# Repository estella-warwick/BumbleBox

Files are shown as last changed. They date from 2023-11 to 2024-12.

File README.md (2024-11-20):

# The BumbleBox: an open-source platform for collecting and quantifying behavior in bumblebees

MastersFigure1final_lowres

https://github.com/Crall-Lab/BumbleBox/assets/102829182/df6746e8-be8d-474d-97e5-7dcfe8cf2d3f

https://github.com/Crall-Lab/BumbleBox/assets/102829182/92d87284-6381-4c2a-ad78-1d7bee3951b9

## About the BumbleBox

xyz
<br /><br />

## Animations of BumbleBox construction

Youtube link to the animations playlist here: [here](https://www.youtube.com/playlist?list=PLHFFPE_W56kkKZQcCbZdQC42oRvphlQpn)
<br /><br />
## BumbleBox Construction Instructions

See building instructions in a google document [here](https://docs.google.com/document/d/14RvdYWr2pkWZVl2kxIvVvCeMsCQhhuTJNkAIiLYHth8/edit?usp=sharing)
<br /><br />

## Software Installation and Setup

See instruction videos [here](https://www.youtube.com/channel/UCykbaZYtgNcFspMfKnfSwYA)
The below steps 1-4 are walked through in the video tutorials 

### Raspberry Pi Install

<br />

Installed using the following hardware:
- Rasbperry Pi 4b, 8GB RAM
- 32GB SanDisk Ultra SD card
- Monitor with HDMI
- HDMI to micro-HDMI cable

<br />

1. Download Debian Bookworm 64-bit OS onto your SD card using a computer with the Raspberry Pi Imager application (Download the application here: https://www.raspberrypi.com/software/)
   
2. Put the SD card into the Pi's SD card slot, hook the Pi up to a monitor via a micro-HDMI to HDMI cable, and power the Pi on - you should see the operating system load on the screen
   
3. You will need to create a username and password for the Raspberry Pi - IMPORTANT: use 'pi' for the username, and some password you'll remember

4. Change your computer hostname to " bumblebox-XX " ex. " bumblebox-01 " or " bumblebox-11 " if you don't know how to do this on the Raspberry Pi, see this [video](https://www.youtube.com/watch?v=NSkHLyY-83s) 
   
5. Open a terminal window (look for a button on the top left of the screen that looks like a black box with a blue top and white text inside it showing '>_')

6. We're now going to install the required software to use the BumbleBox code. For each of the following commands, type the command (or copy and paste) into the terminal window, and then press enter. Once you enter the command, the computer may take some time to download the required software, and will show a lot of text on the screen. Wait for each command to finish running before attempting to run the next command.

<br /><br />

```bash
pip3 install opencv-contrib-python --break-system-packages
```

```bash
pip3 install pandas --break-system-packages
```

```bash
pip3 install scipy --break-system-packages
```

```bash
pip3 install python-crontab --break-system-packages
```

```bash
pip3 install scikit-video --break-system-packages
```

```bash
pip3 install dask --break-system-packages
```
<br />
Amazing! You have now downloaded all the necessary packages to run the BumbleBox on the Raspberry Pi.
<br /><br />
6. Next, download the BumbleBox code onto your Raspberry Pi.  To download the code, click the green 'Code' button on the main BumbleBox page and then press the 'Download Zip' button. After downloading the folder onto the Pi and unzipping it, you might want to put the folder onto the Pi's Desktop so you can access it easily.

download-zip-example-github

<br /><br />

### Install labelling software (on a separate computer, not the Raspberry Pi - install instructions tested for Mac and Linux computers so far) - this is included in the software and setup section, but this will only be used after data is collected, so it does not need to be completed prior to using the BumbleBox.

#### The BumbleBox generates nest images daily that can be labelled in order to track different nest components, which can be useful for a variety of interesting research questions. To do this, we need to install the BumbleBox code and the labelling software we will use on a separate computer. 

1. Install BumbleBox code onto your computer, in the same manner as above

2. Open a terminal window on your computer (try typing 'terminal' into your computer search bar to find it, or go to your applications page and search for the terminal app)

3. Type the following command to create what is called a virtual environment, which basically creates an isolated place on your computer to download software so that it won't potentially cause conflicts with other software on your computer. The virtual environment we're creating is called labelme, because we will be downloading software called labelme.

```bash
python3 -m venv labelme
```

4. Now we have to 'go into' the virtual environment that we've created, using this command:

```bash
source labelme/bin/activate
```

Your terminal should now look something like this:

virtual-env-tutorial-pic

Now we're ready to install labelme! Run the following command in the same terminal window after entering the virtual environment:

```bash
pip3 install labelme
```

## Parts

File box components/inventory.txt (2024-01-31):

Laser cut components for 1/8" acrylic
The component files are duplicated as svg, pdf, and dxf files for ease of use by whoever is cutting them. Some laser cutters work better with a particular kind of file format. 

1x clear_top - clear acrylic
1x diffuser_top - clear acrylic
1x opaque_top - white acrylic
1x access_door_wall - white acrylic
1x entrance_wall - white acrylic
2x vent_walls - white acrylic
1x wall - white acrylic
1x feeder_base - white acrylic

The entrance wall file and the wall file are interchangeable depending on whether the entrance
Part is being used or not (ie whether the bees are going to be let out of the nest or not). I recommend cutting both so you have both options.

The diffuser_top file has 2 different laser path intensities - one to cut the top out, and one to score it in a checkerboard pattern. Each laser cutter is different, so it is hard to give direct settings. For the scoring paths of the diffuser_top file, we want a cut probably 1/4 - 1/3 of the way through the clear 1/8" acrylic. We want to avoid warping. For those getting these cut commercially, you should let the people know that about this file.

3D printed components

All parts should be printed with a 0.4mm nozzle at 0.15mm layer height and automatic supports.
For each box we need these number of printed components:

1x base_insert.stl
1x base.stl
4x bottom_wall_connector.3mf
1x camera_mount.3mf
1x custom_box_entrance.3mf
3x entrance_inner_door.3mf
1x imaging_top_side_innie.3mf
1x imaging_top_side_outie.3mf
1x latch_key.stl
2x latch.stl
4x box_foot.3mf
3x outer_door.3mf
4x top_wall_connector.3mf

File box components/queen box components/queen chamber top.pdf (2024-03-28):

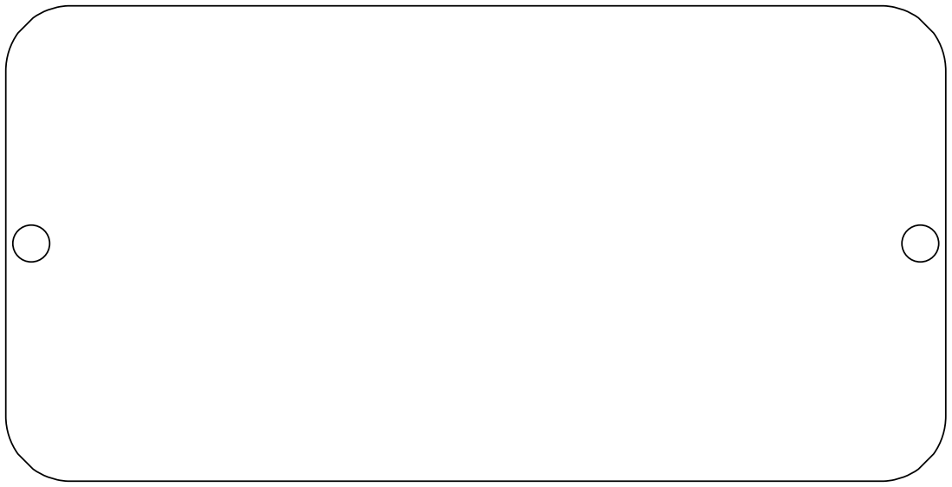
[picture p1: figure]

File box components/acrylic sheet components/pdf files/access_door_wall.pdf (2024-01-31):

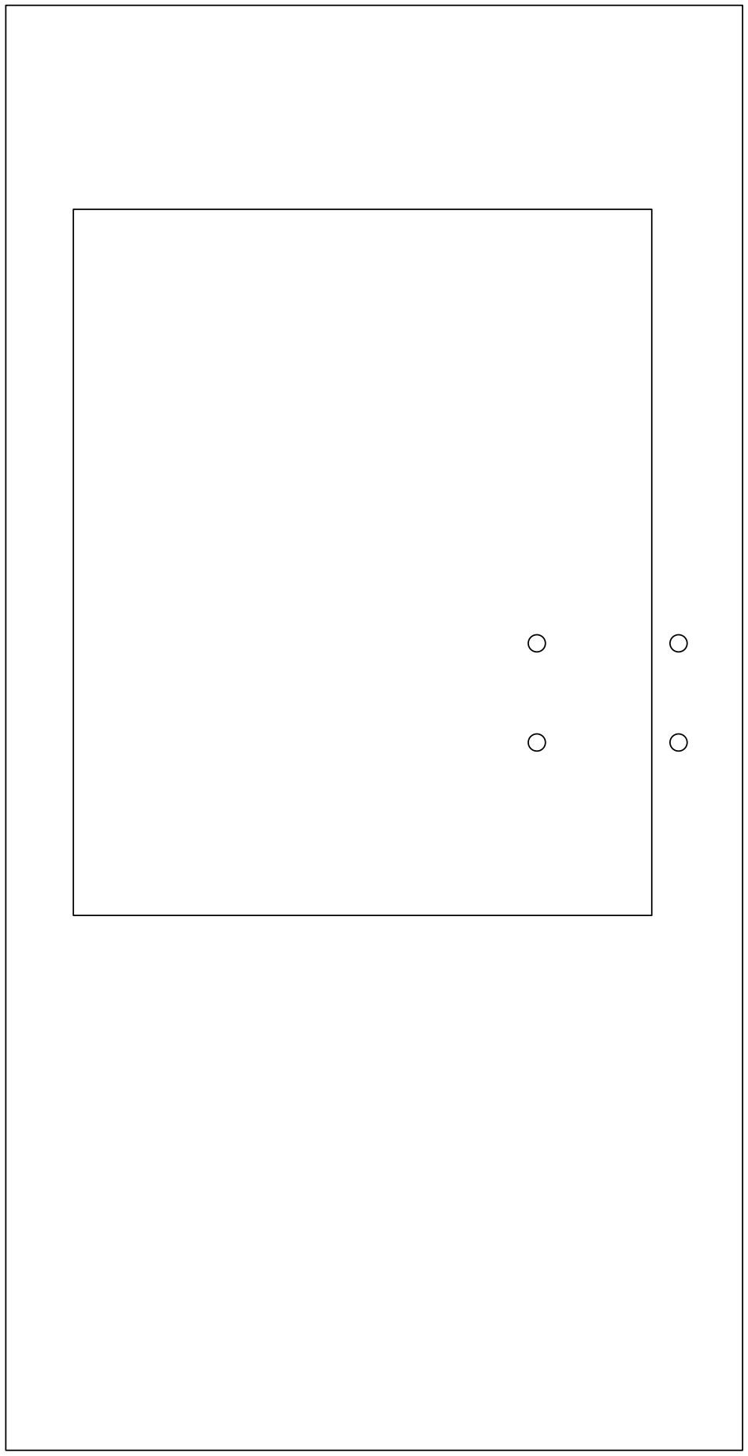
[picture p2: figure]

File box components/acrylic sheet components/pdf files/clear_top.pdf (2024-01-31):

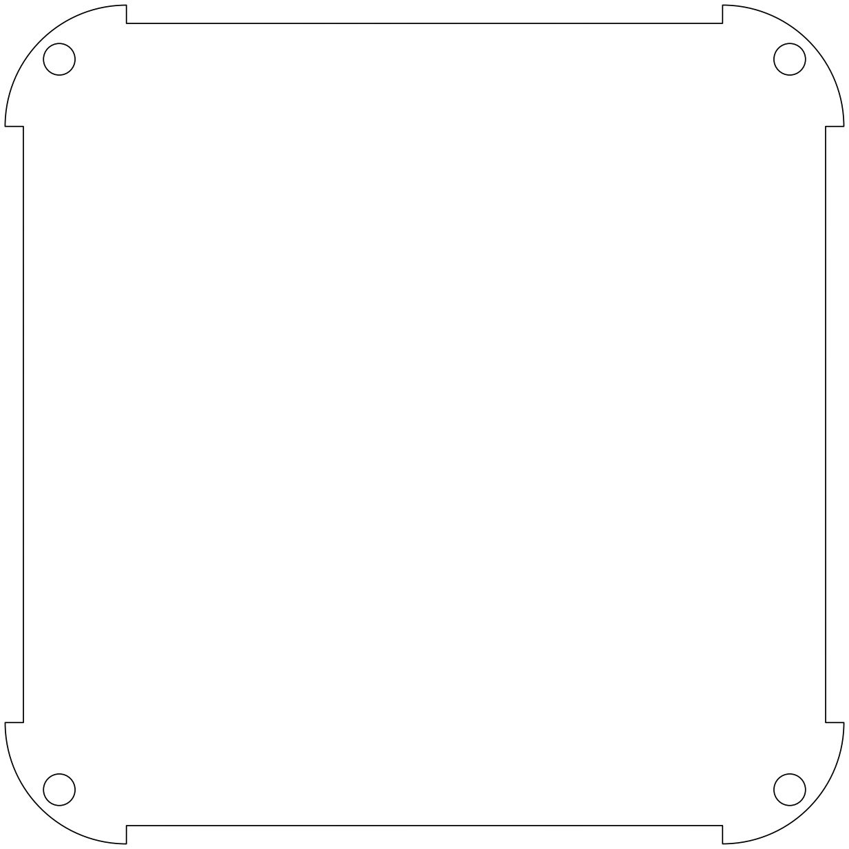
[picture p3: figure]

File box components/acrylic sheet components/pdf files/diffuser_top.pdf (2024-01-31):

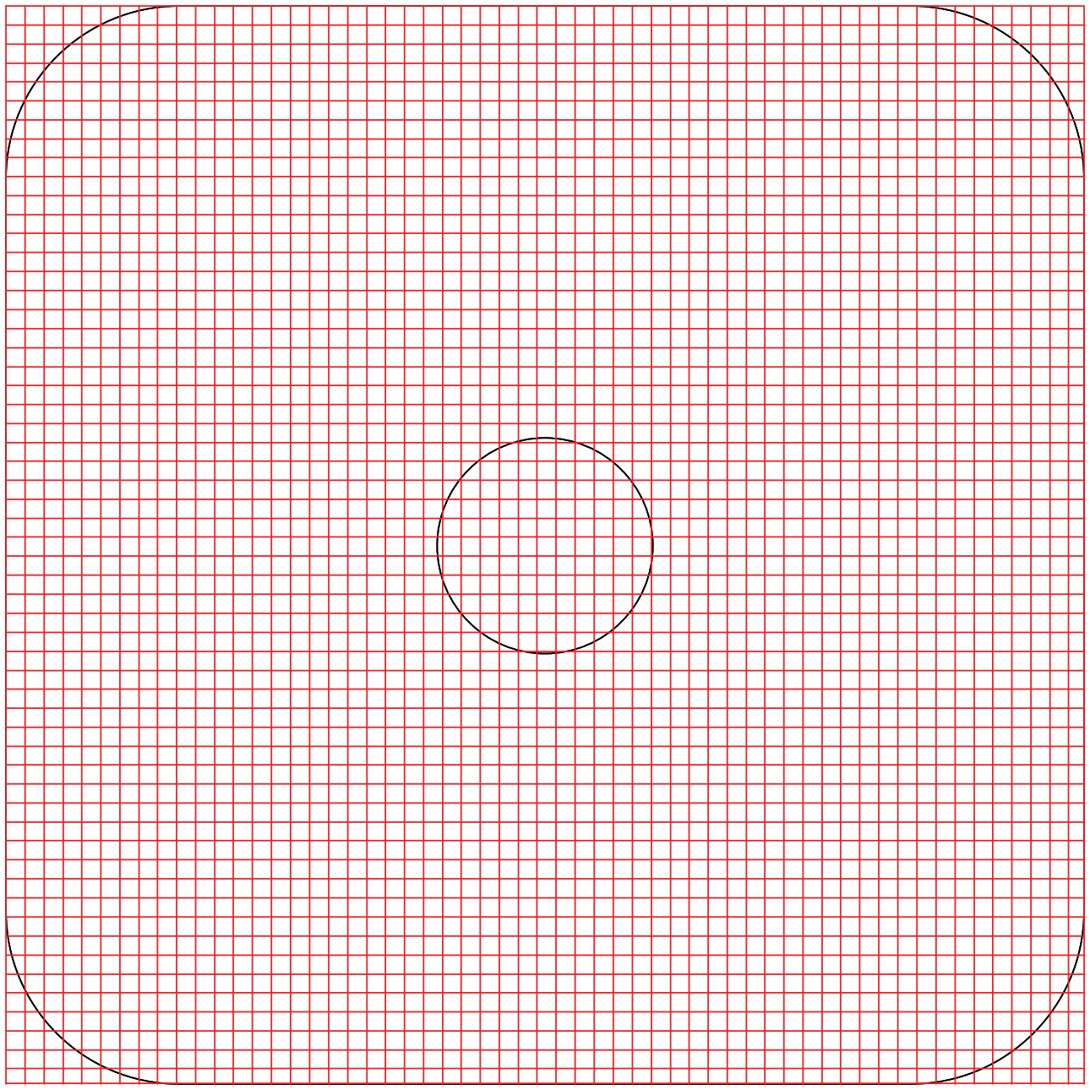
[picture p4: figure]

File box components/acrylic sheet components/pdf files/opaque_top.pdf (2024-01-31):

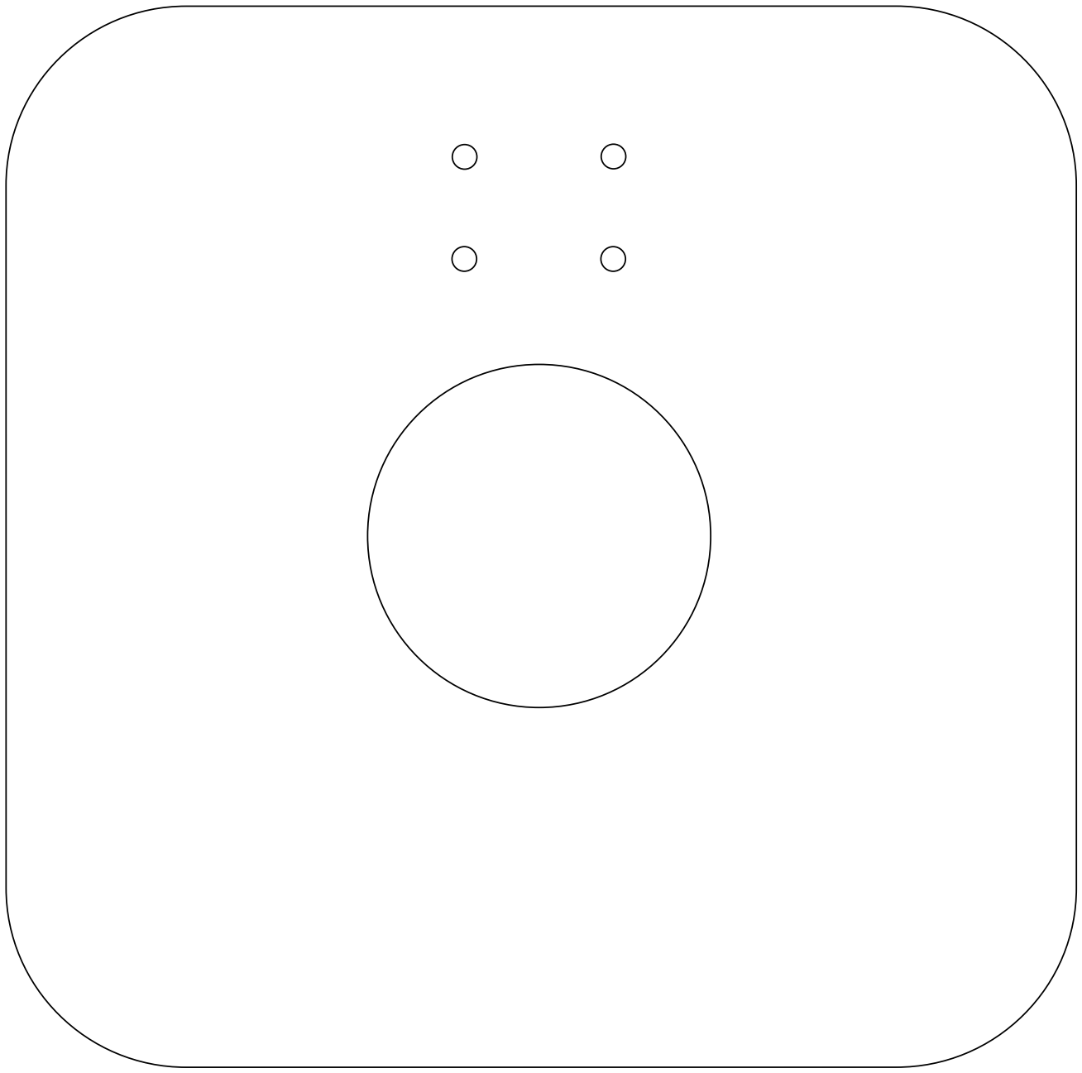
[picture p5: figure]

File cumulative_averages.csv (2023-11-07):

filename | ID | average distance from center | average speed | total tracked frames
bumblebox-01_2023-10-13_18-27-01 | 1 | 572.2 | 8.1 | 82
bumblebox-01_2023-10-13_18-27-01 | 2 | 514.0 | 69.0 | 7
bumblebox-01_2023-10-13_18-27-01 | 3 | 450.0 |  | 2
bumblebox-01_2023-10-13_18-27-01 | 4 | 696.89 | 202.14 | 64
bumblebox-01_2023-10-13_18-27-01 | 6 | 773.0 | 109.33 | 54
bumblebox-01_2023-10-13_18-27-01 | 7 | 376.6 | 19.25 | 26
bumblebox-01_2023-10-13_18-27-01 | 12 | 445.5 | 18.0 | 27
bumblebox-01_2023-10-13_18-27-01 | 13 | 628.38 | 17.75 | 69
bumblebox-01_2023-10-13_18-27-01 | 14 | 243.4 | 17.25 | 32

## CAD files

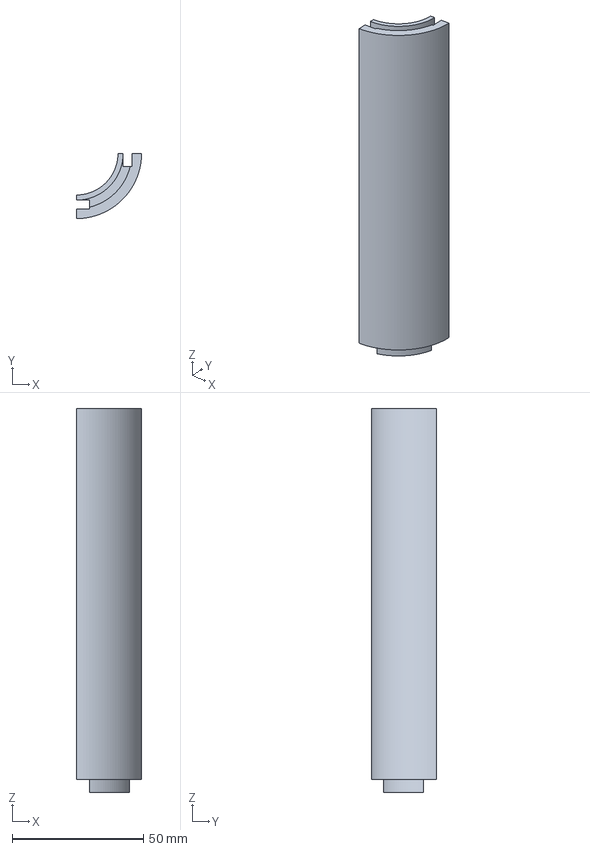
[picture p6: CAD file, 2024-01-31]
box components/3d printed components/bottom_wall_connector.3mf
24.9 x 24.9 x 146.5 mm

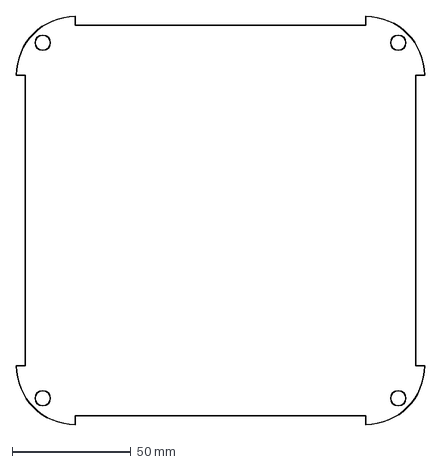
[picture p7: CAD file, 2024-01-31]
box components/acrylic sheet components/dxf files/clear_top.dxf
172.0 x 172.0 mm

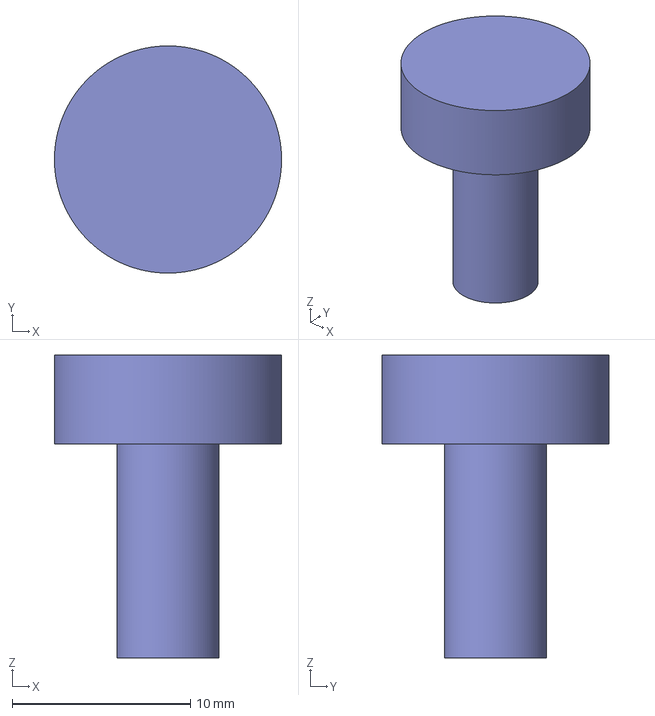
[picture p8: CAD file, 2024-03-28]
box components/queen box components/Queen Nest Plug.3mf
12.7 x 12.7 x 17.0 mm

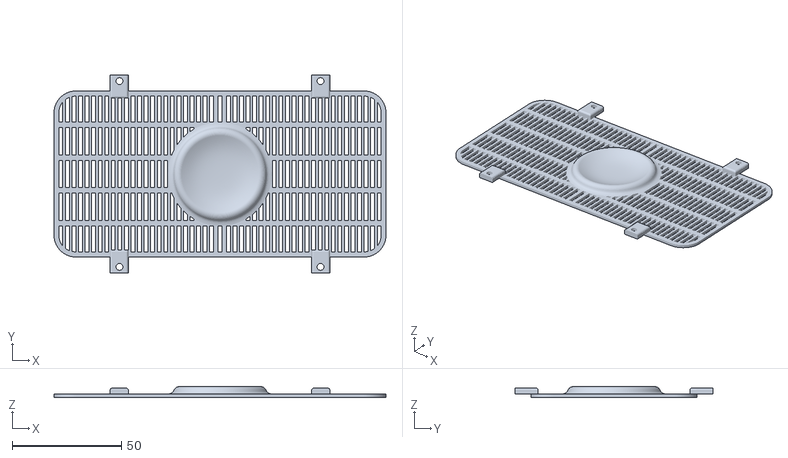
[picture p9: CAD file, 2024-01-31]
box components/3d printed components/base_insert.stl
151.9 x 90.6 x 4.88

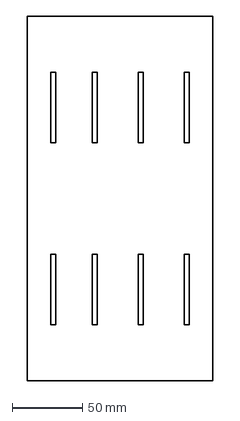
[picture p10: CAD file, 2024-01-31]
box components/acrylic sheet components/dxf files/vent_walls.dxf
132.0 x 259.1 mm

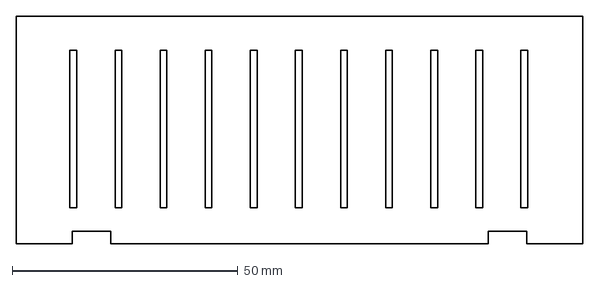
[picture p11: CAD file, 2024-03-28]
box components/queen box components/queen chamber side wall.dxf
125.6 x 50.4 mm

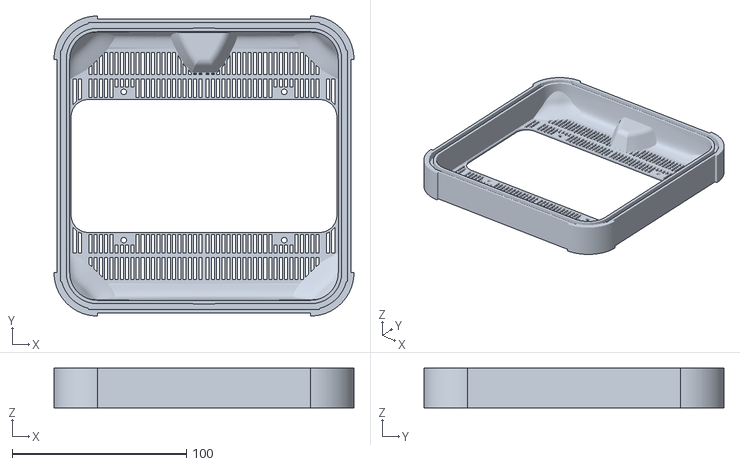
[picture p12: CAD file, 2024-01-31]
box components/3d printed components/base.stl
172.0 x 172.0 x 22.9

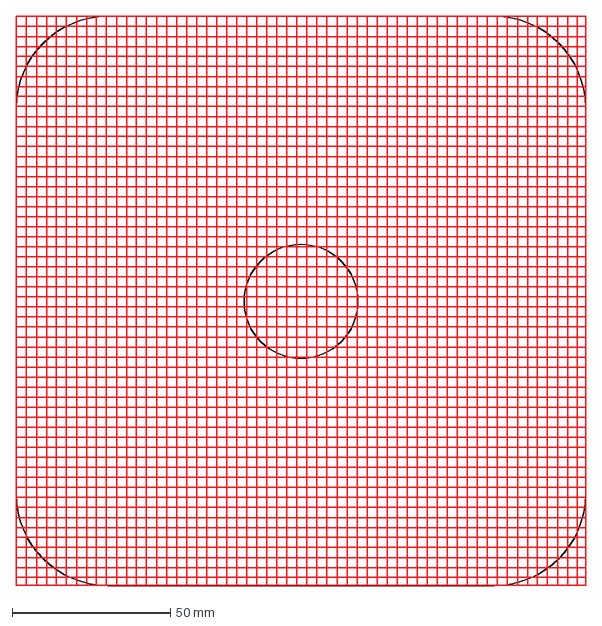
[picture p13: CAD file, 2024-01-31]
box components/acrylic sheet components/dxf files/diffuser_top.dxf
180.1 x 180.1 mm

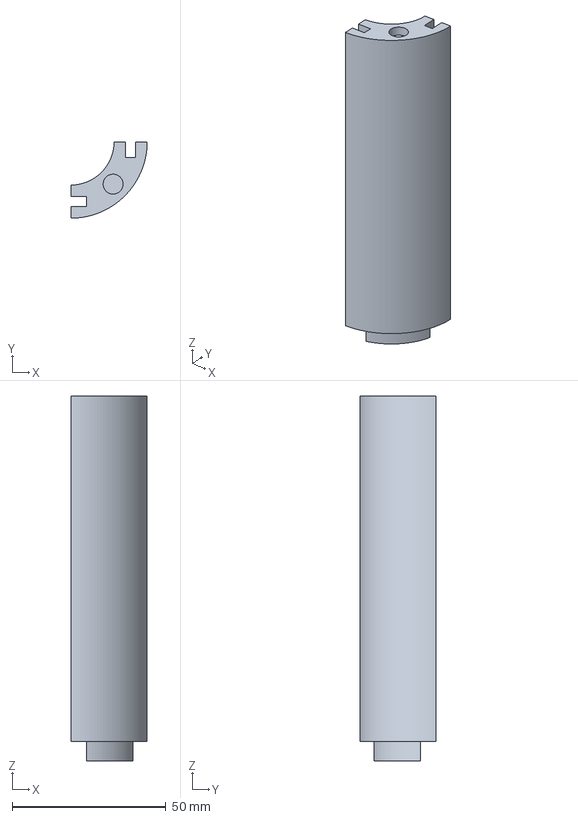
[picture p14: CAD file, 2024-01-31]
box components/3d printed components/top_wall_connector.3mf
24.9 x 24.9 x 118.7 mm

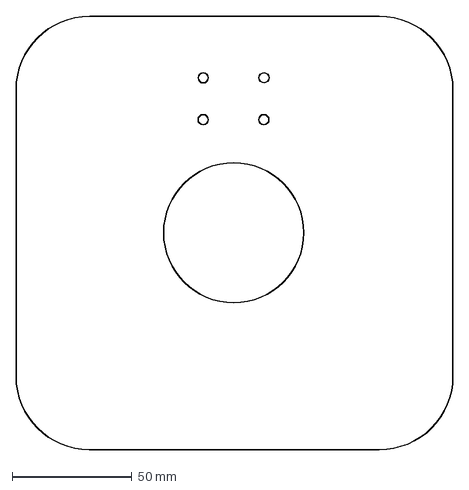
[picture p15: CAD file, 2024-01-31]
box components/acrylic sheet components/dxf files/opaque_top.dxf
182.6 x 181.0 mm

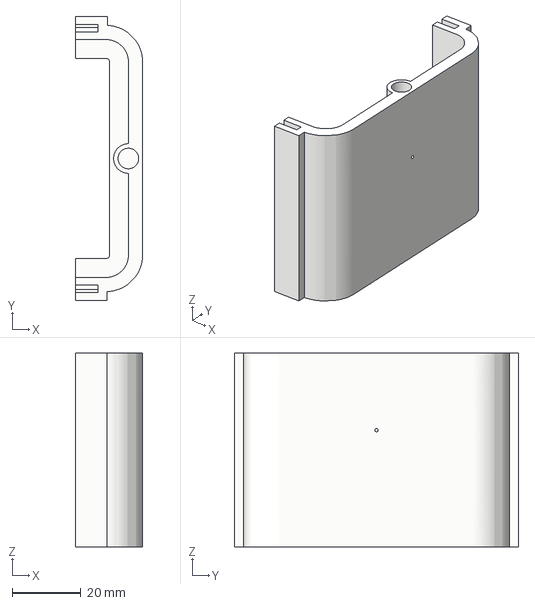
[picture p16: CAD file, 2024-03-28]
box components/queen box components/queen chamber end piece.3mf
19.6 x 82.7 x 56.4 mm

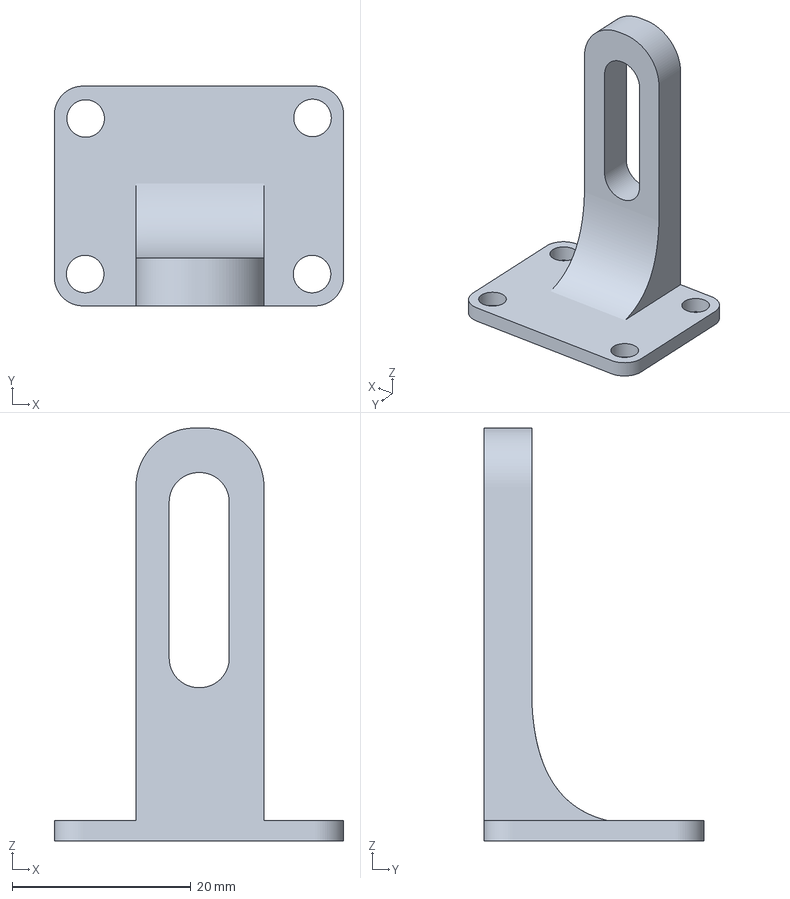
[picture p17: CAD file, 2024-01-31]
box components/3d printed components/camera_mount.3mf
32.4 x 24.6 x 46.2 mm

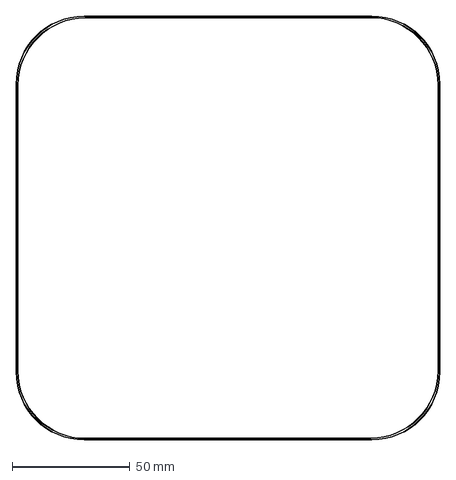
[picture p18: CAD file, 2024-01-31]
box components/acrylic sheet components/dxf files/feeder_base.dxf
180.0 x 180.0 mm

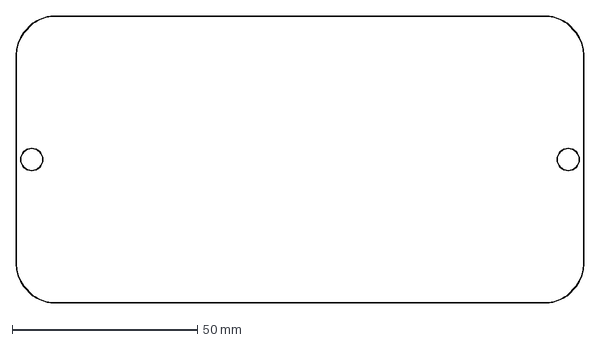
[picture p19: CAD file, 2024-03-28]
box components/queen box components/queen chamber top.dxf
153.1 x 77.4 mm

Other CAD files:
box components/queen box components/base_insert.3mf
box components/3d printed components/latch_key.stl
box components/acrylic sheet components/dxf files/wall.dxf
box components/3d printed components/entrance_inner_door.3mf
box components/3d printed components/box_foot.3mf
box components/3d printed components/custom_box_entrance.3mf
box components/3d printed components/imaging_top_side_innie.3mf
box components/3d printed components/imaging_top_side_outie.3mf
box components/3d printed components/latch.stl
box components/3d printed components/outer_door.3mf
box components/acrylic sheet components/dxf files/access_door_wall.dxf
box components/acrylic sheet components/dxf files/diffuser_top_proto.dxf
box components/acrylic sheet components/dxf files/entrance_wall.dxf

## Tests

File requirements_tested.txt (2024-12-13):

appdirs==1.4.4
arandr==0.1.11
asgiref==3.6.0
astroid==2.14.2
asttokens==2.2.1
attrs==22.2.0
av==10.0.0
Babel==2.10.3
beautifulsoup4==4.11.2
beniget==0.4.1
blinker==1.5
Bottleneck==1.3.5
Brotli==1.0.9
certifi==2022.9.24
chardet==5.1.0
charset-normalizer==3.0.1
click==8.1.3
cloudpickle==3.1.0
colorama==0.4.6
colorzero==2.0
contourpy==1.0.7
cryptography==38.0.4
cupshelpers==1.0
cycler==0.11.0
dask==2024.12.0
dbus-python==1.3.2
decorator==5.1.1
defusedxml==0.7.1
dill==0.3.6
distro==1.8.0
docutils==0.19
et-xmlfile==1.0.1
Flask==2.2.2
fonttools==4.38.0
fs==2.4.16
fsspec==2024.10.0
gast==0.5.2
gpiozero==2.0
html5lib==1.1
idna==3.3
importlib_metadata==8.5.0
iniconfig==1.1.1
isort==5.6.4
itsdangerous==2.1.2
jdcal==1.0
jedi==0.18.2
Jinja2==3.1.2
jsonschema==4.10.3
kiwisolver==0.0.0
lazy-object-proxy==1.9.0
lgpio==0.2.2.0
libarchive-c==2.9
libevdev==0.5
locket==1.0.0
logilab-common==1.9.8
lxml==4.9.2
lz4==4.0.2+dfsg
MarkupSafe==2.1.2
matplotlib==3.6.3
mccabe==0.7.0
meson==1.0.1
more-itertools==8.10.0
mpmath==0.0.0
mypy==1.0.1
mypy-extensions==0.4.3
numexpr==2.8.4
numpy==1.24.2
oauthlib==3.2.2
odfpy==1.4.2
olefile==0.46
opencv-contrib-python==4.5.5.64
openpyxl==3.0.9
packaging==23.0
pandas==1.5.3
parso==0.8.3
partd==1.4.2
pexpect==4.8.0
pgzero==1.2
picamera2==0.3.23
pidng==4.0.9
piexif==1.1.3
pigpio==1.78
Pillow==9.4.0
platformdirs==2.6.0
pluggy==1.0.0+repack
ply==3.11
psutil==5.9.4
ptyprocess==0.7.0
py==1.11.0
PyAudio==0.2.13
pycairo==1.20.1
pycryptodomex==3.11.0
pycups==2.0.1
pygame==2.1.2
Pygments==2.14.0
PyGObject==3.42.2
pyinotify==0.9.6
PyJWT==2.6.0
pylint==2.16.2
PyOpenGL==3.1.6
pyOpenSSL==23.0.0
pyparsing==3.0.9
PyQt5==5.15.9
PyQt5-sip==12.11.1
pyrsistent==0.18.1
pyserial==3.5
pysmbc==1.0.23
pytest==7.2.1
python-apt==2.6.0
python-crontab==3.2.0
python-dateutil==2.8.2
python-dotenv==0.21.0
python-prctl==1.8.1
pythran==0.11.0
pytz==2022.7.1
pyudev==0.24.0
PyYAML==6.0.2
reportlab==3.6.12
requests==2.28.1
requests-oauthlib==1.3.0
responses==0.18.0
roman==3.3
RPi.GPIO==0.7.1a4
RTIMULib==7.2.1
scikit-video==1.1.11
scipy==1.10.1
Send2Trash==1.8.1b0
sense-hat==2.6.0
simplejpeg==1.6.6
simplejson==3.18.3
six==1.16.0
smbus2==0.4.2
soupsieve==2.3.2
spidev==3.5
ssh-import-id==5.10
sympy==1.11.1
systemd-python==235
tables==3.7.0
thonny==4.1.4
toml==0.10.2
tomlkit==0.11.7
toolz==1.0.0
tqdm==4.64.1
twython==3.8.2
types-aiofiles==22.1
types-annoy==1.17
types-appdirs==1.4
types-aws-xray-sdk==2.10
types-babel==2.11
types-backports.ssl-match-hostname==3.7
types-beautifulsoup4==4.11
types-bleach==5.0
types-boto==2.49
types-braintree==4.17
types-cachetools==5.2
types-caldav==0.10
types-certifi==2021.10.8
types-cffi==1.15
types-chardet==5.0
types-chevron==0.14
types-click-spinner==0.1
types-colorama==0.4
types-commonmark==0.9
types-console-menu==0.7
types-contextvars==2.4
types-croniter==1.3
types-cryptography==3.3
types-D3DShot==0.1
types-dateparser==1.1
types-DateTimeRange==1.2
types-decorator==5.1
types-Deprecated==1.2
types-dj-database-url==1.0
types-docopt==0.6
types-docutils==0.19
types-editdistance==0.6
types-emoji==2.1
types-entrypoints==0.4
types-first==2.0
types-flake8-2020==1.7
types-flake8-bugbear==22.10.27
types-flake8-builtins==2.0
types-flake8-docstrings==1.6
types-flake8-plugin-utils==1.3
types-flake8-rst-docstrings==0.2
types-flake8-simplify==0.19
types-flake8-typing-imports==1.14
types-Flask-Cors==3.0
types-Flask-SQLAlchemy==2.5
types-fpdf2==2.5
types-gdb==12.1
types-google-cloud-ndb==1.11
types-hdbcli==2.14
types-html5lib==1.1
types-httplib2==0.21
types-humanfriendly==10.0
types-invoke==1.7
types-JACK-Client==0.5
types-jmespath==1.0
types-jsonschema==4.17
types-keyboard==0.13
types-ldap3==2.9
types-Markdown==3.4
types-mock==4.0
types-mypy-extensions==0.4
types-mysqlclient==2.1
types-oauthlib==3.2
types-openpyxl==3.0
types-opentracing==2.4
types-paho-mqtt==1.6
types-paramiko==2.11
types-parsimonious==0.10
types-passlib==1.7
types-passpy==1.0
types-peewee==3.15
types-pep8-naming==0.13
types-Pillow==9.3
types-playsound==1.3
types-polib==1.1
types-prettytable==3.4
types-protobuf==3.20
types-psutil==5.9
types-psycopg2==2.9
types-pyaudio==0.2
types-PyAutoGUI==0.9
types-pycurl==7.45
types-pyfarmhash==0.3
types-pyflakes==2.5
types-Pygments==2.13
types-pyinstaller==5.6
types-PyMySQL==1.0
types-pynput==1.7
types-pyOpenSSL==22.1
types-pyRFC3339==1.1
types-PyScreeze==0.1
types-pysftp==0.2
types-pytest-lazy-fixture==0.6
types-python-crontab==2.6
types-python-dateutil==2.8
types-python-gflags==3.1
types-python-jose==3.3
types-python-nmap==0.7
types-python-slugify==6.1
types-pytz==2022.6
types-pyvmomi==7.0
types-pywin32==304
types-PyYAML==6.0
types-redis==4.3
types-regex==2022.10.31
types-requests==2.28
types-retry==0.9
types-Send2Trash==1.8
types-setuptools==65.5
types-simplejson==3.17
types-singledispatch==3.7
types-six==1.16
types-slumber==0.7
types-SQLAlchemy==1.4.43
types-stdlib-list==0.8
types-stripe==3.5
types-tabulate==0.9
types-termcolor==1.1
types-toml==0.10
types-toposort==1.7
types-tqdm==4.64
types-tree-sitter==0.20
types-tree-sitter-languages==1.5
types-ttkthemes==3.2
types-typed-ast==1.5
types-tzlocal==4.2
types-ujson==5.5
types-urllib3==1.26
types-vobject==0.9
types-waitress==2.1
types-whatthepatch==1.0
types-xmltodict==0.13
types-xxhash==3.0
types-zxcvbn==4.4
typing_extensions==4.4.0
tzdata==2024.2
ufoLib2==0.14.0
ufw==0.36.2
urllib3==1.26.12
v4l2-python3==0.3.4
webencodings==0.5.1
Werkzeug==2.2.2
wrapt==1.14.1
zipp==3.21.0

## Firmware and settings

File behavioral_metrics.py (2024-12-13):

#!/usr/bin/env python

import pandas as pd
import numpy as np
import logging
import setup
from datetime import datetime as dt
from datetime import date
import os
from scipy import spatial
import glob
from data_cleaning import interpolate

#Enter a folder path to run this script on data youve already collected without calculating behavior metrics. Type the path to the parent folder of your data
folder_path = '/mnt/bumblebox/data' #Otherwise it should be set to None

logger = logging.getLogger(__name__)
logger.setLevel(logging.INFO)
logger.debug("importing behavioral metrics")

def compute_speed(df: pd.DataFrame, fps: int, speed_cutoff_seconds: int, moving_threshold: float, todays_folder_path: str, filename: str) -> pd.DataFrame:

    speed_cutoff_frames = fps*speed_cutoff_seconds
    # Sorting by ID and frame ensures that we compare positions of the same bee across consecutive frames
    df_sorted = df.sort_values(by=['ID', 'frame'])

    # Compute the difference between consecutive rows for centroidX and centroidY
    df_sorted['deltaX'] = df_sorted.groupby('ID')['centroidX'].diff()
    df_sorted['deltaY'] = df_sorted.groupby('ID')['centroidY'].diff()

    df_sorted['elapsed frames'] = df_sorted.groupby('ID')['frame'].diff()
    # Compute the Euclidean distance, which gives speed (assuming frame rate is constant)
    sub_df = df_sorted[ df_sorted['elapsed frames'] < speed_cutoff_frames ]
    sub_df['speed'] = np.sqrt(sub_df['deltaX']**2 + sub_df['deltaY']**2)

    #only calculate speed when moving, otherwise mark as NAN
    sub_df.loc[sub_df['speed'] < 3.16, 'speed'] = np.nan

    df_sorted.loc[:, 'speed'] = sub_df.loc[:, 'speed']
    # Drop temporary columns used for computations
    df_sorted.drop(columns=['deltaX', 'deltaY'], inplace=True)
    df_sorted.to_csv(todays_folder_path + "/" + filename + '_updated.csv', index=False)
    return df_sorted

def compute_activity(df: pd.DataFrame, fps: int, speed_cutoff_seconds: int, moving_threshold: float, todays_folder_path: str, filename: str) -> pd.DataFrame:

    speed_cutoff_frames = fps*speed_cutoff_seconds
    # Sorting by ID and frame ensures that we compare positions of the same bee across consecutive frames
    df_sorted = df.sort_values(by=['ID', 'frame'])

    # Compute the difference between consecutive rows for centroidX and centroidY
    df_sorted['deltaX'] = df_sorted.groupby('ID')['centroidX'].diff()
    df_sorted['deltaY'] = df_sorted.groupby('ID')['centroidY'].diff()

    df_sorted['elapsed frames'] = df_sorted.groupby('ID')['frame'].diff()
    # Compute the Euclidean distance, which gives speed (assuming frame rate is constant)
    sub_df = df_sorted[ df_sorted['elapsed frames'] < speed_cutoff_frames ]
    sub_df['activity'] = np.sqrt(sub_df['deltaX']**2 + sub_df['deltaY']**2) #Calculating speed here - we threshold for activity below

    sub_df.loc[sub_df['activity'] < moving_threshold, 'activity'] = 0
    sub_df.loc[sub_df['activity'] <= moving_threshold, 'activity'] = 1

    df_sorted.loc[:, 'activity'] = sub_df.loc[:, 'activity']
    # Drop temporary columns used for computations
    df_sorted.drop(columns=['deltaX', 'deltaY'], inplace=True)
    df_sorted.to_csv(todays_folder_path + "/" + filename + '_updated.csv', index=False)
    return df_sorted

def compute_social_center_distance(df: pd.DataFrame, todays_folder_path: str, filename: str) -> pd.DataFrame:
    # Compute the social center for each frame
    social_centers = df.groupby('frame')[['centroidX', 'centroidY']].mean()
    social_centers.columns = ['centerX', 'centerY']

    # Merge the social centers with the main dataframe to calculate distances
    df = df.merge(social_centers, left_on='frame', right_index=True)

    # Compute the distance of each bee from the social center of its frame
    df['distance_from_center'] = np.sqrt((df['centroidX'] - df['centerX'])**2 + (df['centroidY'] - df['centerY'])**2)

    # Drop temporary columns used for computations
    df.drop(columns=['centerX', 'centerY'], inplace=True)
    df_sorted = df.sort_values(by=['frame','ID'])
    df_sorted.to_csv(todays_folder_path + "/" + filename + '_updated.csv', index=False)
    return df_sorted


# function to calculate the average distance of each bee to every other tagged bee by frame of video
def video_avg_min_max_distances(pairwise_distance_df):

    avg_pd_df = 'None'

    pairwise_v1 = pairwise_distance_df.drop(columns={'ID','frame'}) #drop non-data columns from new dataframe in order to calculate the min, max of the data without interference
    pairwise_distance_df['avg_distance'] = pairwise_v1.mean(axis=1, numeric_only=True, skipna=True)
    pairwise_distance_df['min_distance'] = pairwise_v1.min(axis=1, numeric_only=True, skipna=True) #makes sure to get the min from each row, excluding nans
    pairwise_distance_df['max_distance'] = pairwise_v1.max(axis=1, numeric_only=True, skipna=True)

    return pairwise_distance_df


def pairwise_distance(df: pd.DataFrame, todays_folder_path: str, filename: str) -> pd.DataFrame:

    video_pd_df = 'None'
    for frame_num, frame_df in df.groupby(['frame']): #now for the subdataframe of each frame of a video of a colony, reset the index so its not a multiindex

        xy_array = frame_df[['centroidX','centroidY']].to_numpy() #make these two columns into an array of [x,y] for numpy to use
        dist_matrix = spatial.distance.pdist(xy_array)
        squareform = spatial.distance.squareform(dist_matrix) #turns the pairwise distance vector into a 2d array (which has double values but allows us to do row based operations)
        squareform[ squareform == 0 ] = np.nan
        pairwise_distance_df = pd.DataFrame(squareform, columns=frame_df['ID']) #make the squareform array into a dataframe, with the bee IDs as the columns
        bee_id_column = frame_df.loc[:,'ID'].reset_index(drop=True) #make a new bee ID column to add to the dataframe
        pairwise_distance_df.insert(0, 'ID', bee_id_column)
        pairwise_distance_df.columns.name = None #this stops bee ID showing up as the name of all the columns in the df, it looks weird and is confusing
        pairwise_distance_df['frame'] = int(frame_num)#[0])
        #pairwise_distance_df = pd.concat((frame_df['bee ID'], pd.DataFrame(squareform, columns=frame_df['bee ID'])), axis=1) #turns the squareform array into a dataframe indexed by bee ID
        #pairwise_distance_df.replace(0, np.nan, inplace=True) #replace zeros with nan values in order to exclude them from calculations

        try:
            pairwise_distance_df['ID'] = pairwise_distance_df['ID'].astype('int')
        except ValueError:
            print('ValueError: are there any Nans in the bee IDs? Why would there be though...')
            print(frame_num, frame_df)
            return pairwise_distance_df['ID']

        if 'None' in video_pd_df:
            #print('avg_pd_df is equal to None!')
            video_pd_df = pairwise_distance_df

        else:

            pairwise_distance_df = pairwise_distance_df.loc[~pairwise_distance_df.index.duplicated(),:] #need these two lines to add to video level dataframe for some reason
            pairwise_distance_df = pairwise_distance_df.loc[:,~pairwise_distance_df.columns.duplicated()]
            try:
                video_pd_df = pd.concat([video_pd_df,pairwise_distance_df], axis=0, sort=True) #ignore_index=True)
            except:
                print(f"heres the videos index: {video_pd_df.index}")
                return
    #calculate frame averages, mins, and maxes
    pairwise_distance_df = frame_avg_min_max_distances_to_other_bees(pairwise_distance_df)

    #extract frame_number column to bring it to the front of the df
    frame_column = video_pd_df['frame']
    bee_id_column = video_pd_df['ID']
    #drop the columns
    video_pd_df.drop(labels=['frame', 'ID'], axis=1, inplace=True)

    #then reinsert frame number at the beginning and averages at the end of the dataframe
    video_pd_df.insert(0, 'ID', bee_id_column)
    video_pd_df.insert(0, 'frame', frame_column)
    video_pd_df.reset_index(drop=True, inplace=True)
    video_pd_df.to_csv(todays_folder_path + '/' + filename + '_pairwise_distance.csv')

    return video_pd_df


#this function is called within the pairwise distance function and adds the average distance (and min and max) of each bee to every other bee in each frame
def frame_avg_min_max_distances_to_other_bees(pairwise_distance_df):

    pairwise_v1 = pairwise_distance_df.drop(columns={'ID','frame'}) #drop non-data columns from new dataframe in order to calculate the min, max of the data without interference
    pairwise_distance_df['avg_distance'] = pairwise_v1.mean(axis=1, numeric_only=True, skipna=True)
    pairwise_distance_df['min_distance'] = pairwise_v1.min(axis=1, numeric_only=True, skipna=True) #makes sure to get the min from each row, excluding nans
    pairwise_distance_df['max_distance'] = pairwise_v1.max(axis=1, numeric_only=True, skipna=True)

    return pairwise_distance_df


def contact_matrix(df: pd.DataFrame, todays_folder_path: str, pixel_contact_distance, filename: str):

    if df is None:
        return 1
    df_copy = df.copy() # make a copy to store the bee ID and frame number columns, which will be changed to a 1 or 0 in the original dataframe
    df[ df <= pixel_contact_distance ] = 1
    df[ df > pixel_contact_distance ] = 0
    df['ID'] = df_copy['ID'] # add the correct column back in by overwriting 'bee ID'
    df['frame'] = df_copy['frame'] # add the correct column back in by overwriting 'frame number'

    df.to_csv(todays_folder_path + '/' + filename + '_contacts.csv')

    return df


def summary_contact_df(contact_df):

    if type(contact_df) == 1:
        return 1

    contact_df.drop(columns={'frame'}, inplace=True)
    video_summary_contact_df = contact_df.groupby('ID').sum()
    video_summary_contact_df.to_csv(todays_folder_path + '/' + filename + 'summary_contacts.csv')
    return video_summary_contact_df



def compute_video_averages(df: pd.DataFrame, todays_folder_path: str, filename: str) -> pd.DataFrame:
    print('computing averages')
    # Setup logging
    df_sorted = df.sort_values(by=['ID','frame'])
    average_distances = df_sorted.groupby('ID')['distance_from_center'].mean()
    average_speed = df_sorted.groupby('ID')['speed'].mean()
    speed_count = df_sorted.groupby('ID')['speed'].count()
    frame_count = df_sorted.groupby('ID')['ID'].count()
    #datetime = df_sorted['datetime']
    video_tally = pd.DataFrame({'filename': filename,
                                  'average distance from center': round(average_distances),
                                  'average speed': round(average_speed),
                                  'frames tracked in video':frame_count})
    video_tally.reset_index(inplace=True)
	#rearrange columns so filename comes first
    try:
        video_tally = video_tally[['filename','ID','average distance from center','average speed','frames tracked in video']]
    except Exception as e:
        logger.debug("Exception occurred: %s", str(e))
    try:
        video_tally.to_csv(f'{todays_folder_path}/{filename}_averages.csv', mode='w', index=False, header=True)
        logger.debug(f"data written to {todays_folder_path}/{filename}_averages.csv', but as a 1D list:\n%s", str(video_tally.values.flatten()))
    except Exception as e:
        logger.debug("Exception occurred: %s", str(e))
    return video_tally






def compile_dfs(directory_path, start_filename = None, end_filename = None, format = None, end_of_filename = 'averages.csv'):
    #not done yet!
    if format == None:
        format = '%Y-%m-%d_%H-%M-%S'

    if start_filename != None:
        hostname, date, time, ext = start_filename.split("_")
        start_datetime = date + "_" + time
        start_datetime = dt.strptime(start_datetime, format)

    if end_filename != None:
        hostname2, date2, time2, ext2 = end_filename.split("_")
        end_datetime = date2 + "_" + time2
        end_datetime = dt.strptime(end_datetime, format)

    df_list = []

    if start_filename != None and end_filename != None:
        for paths, dirs, files in os.walk(directory_path):
            for path in paths:
                for filename in files:
                    hostname3, date3, time3, ext3 = file.split("_")
                    if ext3 == end_of_filename:
                        datetime = date3 + time3
                        datetime = datetime.strptime(datetime, format)

                        if start_datetime <= datetime <= end_datetime:
                            print(path)
                            df = pd.DataFrame(path)







def store_cumulative_averages(filename: str):
    #finished?
    #datetimes need to be strings in this format: "yyyy-mm-dd_HH-MM-SS"

    #if type(start_datetime) == str and type(end_datetime) == str:
    #    try:
    #        start_filename =
    #        end_filename =


    print('computing cumulative averages')
    try:
        df = pd.read_csv('behavior_quantification.csv', index_col=None, header=0)
    except Exception as e:
        logger.debug("Exception occurred: %s", str(e))

    try:
        df_sorted = df.sort_values(by=['ID'])
    except Exception as e:
        logger.debug("Exception occurred: %s", str(e))

    average_distances = df_sorted.groupby('ID')['average distance from center'].mean()
    average_speed = df_sorted.groupby('ID')['average speed'].mean()
    frame_count = df_sorted.groupby('ID')['frames tracked in video'].sum()
    df_sorted2 = df.sort_values(by=['filename'])
    latest_filename = df_sorted2['filename'].iloc[-1]
    logger.info("latest_filename: %s", latest_filename)
    cumulative_tally = pd.DataFrame({'filename': latest_filename,
                                  'average distance from center': round(average_distances,2),
                                  'average speed': round(average_speed,2),
                                  'total tracked frames':frame_count})
    cumulative_tally.reset_index(inplace=True, drop=False)
    try:
        cumulative_tally = cumulative_tally[['filename','ID','average distance from center','average speed','total tracked frames']]
    except Exception as e:
        logger.debug("Exception occurred: %s", str(e))
    try:
        cumulative_tally.to_csv('cumulative_averages.csv', mode='w', index=False, header=True)
    except Exception as e:
        logger.debug("Exception occurred: %s", str(e))

    return cumulative_tally


def calculate_behavior_metrics(df, actual_frames_per_second, moving_threshold, todays_folder_path, filename): #accept a path to a file or a path to a dataframe

    print("starting calculations")
    #not finished!
    if type(df) == str: #path to csv file
        df = pd.read_csv(df, header=0)
        print("Reading csv")

    elif type(df) == pd.DataFrame: #dataframe
        #df = data_object
        print("Its a dataframe!")

    if "speed" in setup.behavior_metrics:
        print("Trying speed")
        #try:
        df = compute_speed(df,actual_frames_per_second,4, moving_threshold, todays_folder_path, filename)
        print('just computed speed')
        #except Exception as e:
        #    print("Exception occurred: %s", str(e))
        #    logger.debug("Exception occurred: %s", str(e))

    if "activity" in setup.behavior_metrics:
        print("Trying activity")
        df = compute_activity(df,actual_frames_per_second,4, moving_threshold, todays_folder_path, filename)
        print("Just computed activity")

    if "distance from center" in setup.behavior_metrics:
        print("Trying distance from center")
        try:
            df = compute_social_center_distance(df, todays_folder_path, filename)
            print('just computed distance from center')
        except Exception as e:
            print("Exception occurred: %s", str(e))
            logger.debug("Exception occurred: %s", str(e))


    if "pairwise distance" in setup.behavior_metrics:
        print("Trying pairwise distance")
        #try:
        pw_df = pairwise_distance(df, todays_folder_path, filename)
        #except Exception as e:
        #    print("Exception occurred: %s", str(e))
        #    logger.debug("Exception occurred: %s", str(e))


    if "contacts" in setup.behavior_metrics:
        print("Trying contacts")
        #try:
        contact_df = contact_matrix(pw_df, todays_folder_path, setup.pixel_contact_distance, filename)
        #except Exception as e:
        #    logger.debug("Exception occurred: %s", str(e))

    if "video averages" in setup.behavior_metrics:
        try:
            video_averages = compute_video_averages(df, todays_folder_path, filename)
            print('just computed video averages!')
        except Exception as e:
            print("Exception occurred: %s", str(e))
            logger.debug("Exception occurred: %s", str(e))


    if "cumulative averages" in setup.behavior_metrics:
        try:
            running_averages = store_cumulative_averages(filename)
            print('just computed running averages!')
        except Exception as e:
            print("Exception occurred: %s", str(e))
            logger.debug("Exception occurred: %s", str(e))

            if running_averages.empty == True:
                pass


if __name__ == '__main__':

    print(f"Run this script to calculate behavioral metrics on a set of data! Im looking for data in:\n\n{todays_folder_path}\n\nThis is todays data folder.\nDo you want to use a different folder?")
    print("\n")
    yes_or_no = input("Enter yes or no: ")

    while yes_or_no != "yes" and yes_or_no != "no":
        print("Do you want to use a different folder?")
        yes_or_no = input("Please enter either yes or no, all lowercase: ")

    if yes_or_no == "yes":
        print("Type the new path without a trailing \"/\" after the folder name - Example: /mnt/bumblebox/data/2023-10-23")
        todays_folder_path = input("Folder path: ")
        print(f"Using {todays_folder_path}. Moving on!")

    elif yes_or_no == "no":
        print("Moving on, then!")

    else:
        print("Type yes or no, all lowercase. Try again!")

    for file in glob.glob(folder_path + '/**/*_raw.csv', recursive=True):
        print(file)
        head, tail = os.path.split(file)
        filename1, filename2, filename3, ext = tail.split('_',3)
        filename = filename1 + '_' + filename2 + '_' + filename3

        try:
            df = pd.read_csv(file)
        except Exception as e:
            print("Exception occurred: %s", str(e))
            continue

        ''' check whether files have been interpolated yet or not '''
        if setup.interpolate_data == True:
            df = interpolate(df, setup.max_seconds_gap, setup.actual_frames_per_second)
        calculate_behavior_metrics(df,setup.actual_frames_per_second,setup.moving_threshold,head,filename)

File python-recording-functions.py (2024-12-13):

#!/usr/bin/env python

from picamera2 import Picamera2, Preview
from picamera2.encoders import JpegEncoder
from picamera2.encoders import H264Encoder
from sys import getsizeof
import time
import numpy as np
import cv2
from PIL import Image
import os
import subprocess
import ffmpeg

def picam2_record_mjpeg(filename, outdir, recording_time=20, quality=95, size=(4056,3040), imformat="RGB888", fps=4, buffer_count=2):
	frame_duration_us = int(1/fps * 10**6)
	picam2 = Picamera2()
	video_config = picam2.create_video_configuration(main={"size": size, "format": imformat}, controls={"FrameDurationLimits": (frame_duration_us, frame_duration_us)}, buffer_count=2)
	picam2.align_configuration(video_config)
	picam2.configure(video_config)

	picam2.start_preview()
	encoder = JpegEncoder(q=quality)
	output = outdir+filename

	picam2.start()
	time.sleep(2)
	picam2.start_encoder(encoder,output,pts=outdir+filename+"_pts.txt")
	#picam2.start_recording(encoder,output,pts=outdir+filename+"_pts.txt")

	time.sleep(recording_time)

	picam2.stop()
	picam2.stop_encoder()





def folder_jpgs2mjpeg(dirpath):
	cmd = 'for i in ' + dirpath + '*.jpg: do ffmpeg -i "$i" "${i%.*}.mjpeg"; done'
	os.system(cmd)





def picam2_YUV420array2mjpeg(recording_time=1, quality="maximum", fps=6, outdir='/mnt/bombusbox/burstcapturejpgs/', filename='testpicam2_yuv2vid', imtype="y"): #make options "yuv", "rgb", "y", "all"

	picam2 = Picamera2()
	preview = picam2.create_preview_configuration({"format": "YUV420", "size": (4032,3040)})
	picam2.configure(preview)
	picam2.start()

	time.sleep(2)
	start_time = time.time()

	frames_dict = {}
	i = 0

	print("beginning video capture in picam2_YUV420array2mjpeg()")
	while ( (time.time() - start_time) < recording_time) or (i <= fps*recording_time):
		timestamp = time.time() - start_time

		yuv420 = picam2.capture_array()

		if imtype == "y":
			yuv420 = yuv420[0:3040, :]
		frames_dict[f"frame_{i:03d}"] = [yuv420, timestamp]
		time.sleep(1/(fps+1))
		i += 1
	print(f'finished capturing frames to arrays, captured {i} frames in {time.time()-start_time}')
	sizeof = getsizeof(frames_dict)
	print(f"Size of dictionary storing the frames (in bytes): {sizeof}")

	if imtype =="y":
		for frame_number in frames_dict:
			imlist = frames_dict[frame_number]
			array = imlist[0]
			y_im = Image.fromarray(array, mode="L") #L meaning a single 8-bit channel, greyscale
			y_im.save(outdir+frame_number+".jpg", quality=quality)

	elif imtype =="yuv":
		for frame_number in frames_dict:
			imlist = frames_dict[frame_number]
			array = imlist[0]
			yuv_im = Image.fromarray(array, mode="YCbCr") #YCbCr meaning 3x8-bit channels for YUV
			yuv_im.save(outdir+filename+".jpg", quality=quality)

	elif imtype =="rgb":
		for frame_number in frames_dict:
			imlist = frames_dict[frame_number]
			array = imlist[0]
			yuv_im = Image.fromarray(array, mode="YCbCr")
			rgb_im = cv2.cvtColor(yuv_im, cv2.COLOR_YUV420p2RGB)
			rgb_im.save(outdir+filename+".jpg", quality=quality)

	elif imtype == "all":
		for frame_number in frames_dict:
			imlist = frames_dict[frame_number]
			array = imlist[0]
			yuv_im = Image.fromarray(array, mode="YCbCr")
			y_im = Image.fromarray(array, mode="L")
			rgb_im = cv2.cvtColor(yuv_im, cv2.COLOR_YUV420p2RGB)
			y_im.save(outdir+filename+".jpg", quality=quality)
			yuv_im.save(outdir+filename+".jpg", quality=quality)
			rgb_im.save(outdir+filename+".jpg", quality=quality)

	else:
		print("Error: imtype must equal either 'y', 'yuv', 'rgb', or 'all'")
		return print("Exit code: 1")

	print("now turning the jpgs into an mjpeg video...")
	#cmd = 'for i in ' + outdir + '*.jpg: do ffmpeg -i "$i" "${i%.*}.mjpeg"; done'
	#cmd = 'for i in /mnt/bombusbox/burstcapturejpgs/*.jpg; do ffmpeg -i "$i" "${i%.*}.mjpeg"; done'
	cmd = 'ffmpeg -i /mnt/bombusbox/burstcapturejpgs/*.jpg -vf fps=10 -pix_fmt yuv420p /mnt/bombusbox/burstcapturejpgs/output.mp4'
	os.system(cmd)
	print("Success?")

#def write_jpgs2mp4(numframes, jpgdir='/mnt/bombusbox/burstcapturejpgs', cv2.VideoWriter_fourcc(*'mp4'), fps=10, size=(4032,3040):



def picam2_YUV420arraycapture_timetest(recording_time=10, fps=15, quality="maximum", outdir='/mnt/bombusbox/burstcapturejpgs/', filename='testpicam2_yuv2vid', container="dict",imtype="y"): #make options "yuv", "rgb", "y", "all"

	picam2 = Picamera2()
	preview = picam2.create_preview_configuration({"format": "YUV420", "size": (4032,3040)})
	picam2.configure(preview)
	picam2.start()

	time.sleep(2)
	start_time = time.time()

	frames_dict = {}
	i = 0

	print("beginning video capture in picam2_YUV420arraycapture_timetest()")
	while ( (time.time() - start_time) < recording_time): #or (i <= fps*recording_time):
		timestamp = time.time() - start_time

		yuv420 = picam2.capture_array()

		if imtype=="y" and container=="dict":
			yuv420 = yuv420[0:3040, :]
			frames_dict[f"frame_{i:03d}"] = [yuv420, timestamp]
			#time.sleep(1/(fps+10))
			i += 1

	print(f'finished capturing frames to arrays, captured {i} frames in {time.time()-start_time}')
	sizeof = getsizeof(frames_dict)
	print(f"Size of dictionary storing the frames: {sizeof}")

	for frame in frames_dict:
		print(frame_number, frames_dict[frame_number][1])

	if imtype =="y":
		timestamps = {}
		save_time = time.time()
		for frame_number in frames_dict:
			imlist = frames_dict[frame_number]
			frame_array = imlist[0]
			y_im = Image.fromarray(frame_array, mode="L") #L meaning a single 8-bit channel, greyscale
			y_im.save(outdir+frame_number+".jpg", quality=quality)
			timestamps[frame_number] = time.time() - save_time

		end_time = time.time()

		for frame_number in timestamps:
			print(f'{frame_number}: {timestamps[frame_number]} seconds')

		print(f'wrote {int(len(frames_dict))} images in {end_time - save_time} seconds.\nThats an average of {int(len(frames_dict)) / (end_time - save_time)} frames per second!')











def x265vidwrite(filename, images, framerate=5, vcodec='libx265'):
    if not isinstance(images, np.ndarray):
        images = np.asarray(images)
        print(images.shape)
    n,channels,height,width = images.shape
    process = (
        ffmpeg
            .input('pipe:', format='rawvideo', pix_fmt='yuv420p', r=framerate, s='{}x{}'.format(width, height))
            .output(filename, pix_fmt='yuv420p', vcodec=vcodec)
            .overwrite_output()
            .run_async(pipe_stdin=True)
    )
    for frame in images:
        process.stdin.write(
            frame
                .astype(np.uint8)
                .tobytes()
        )
    process.stdin.close()
    process.wait()
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

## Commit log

2023-06-02 FUNCTIONS STILL EXPERIMENTAL Changed the name to python-recording-functions Instead of storing the frames in a dictionary, have written more functions to store them in a list Working on a function to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
2023-07-20 both mp4 and mjpeg recording are now working! Added argparse functionality to record_mjpeg.py which now houses both mp4 and mjpeg recording - need to change the name still. Working currently on getti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
2023-07-24 have added zoom and noise reduction functionality to the record_video.py and ram_capture_tag_tracking.py functions. Have mostly updated the setup.py script to reflect this, though it needs to be test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
    [ram_capture_tag_tracking.py, record_video.py]
2023-07-27 added initial version of set_crontab.py, though it needs to be tested on a raspberry pi still. tomorrow! also started adding construction dxf files for the boxes
    [clear_top.dxf, diffuser_top.dxf, entrance_wall.dxf]
2023-07-28 adding new box component files and new code files, specifically the nest labeling script and the labelmerc file. going to add things as I break the code to make sure whats needed etc.
    [Latch Key_v2.stl, Latch_v2.stl, Long Box Foot.3mf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]
2023-10-11 added updating behavioral metric scores using two new csv files stored in BumbleBox
    [behavior_quantification.csv, cumulative_averages.csv]
2023-10-31 merges the changes from the three different bumbleboxes (LOL) all now on this one - still need to update the image combining scripts and add that to the label nests scripts, or re-write that altogeth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
    [behavior_quantification.csv, cumulative_averages.csv]
2023-11-07 i dont remember what ive done, oh no I have added a number of behavioral quantification functions. still need to do data cleaning and interpolation
    [behavior_quantification.csv]
2023-11-07 added a print statement of the crontab settings, added a knob to turn off tracking of videos
2024-01-31 Adding 3d and laser cutter files, also modifying the code files, mainly the aruco module files to work with the updated aruco code, and to allow for users to make their username whatever they want. I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
    [access_door_wall.dxf, base.stl, base_insert.stl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]
2024-04-28 Update start_automated_recording.py
    fix USB mounting to /mnt/bumblebox/data folder
    [start_automated_recording.py]
2024-12-13 Various fixes required to get this running on my pi
    - Change some tabs to spaces
    - API for cv2.aruco DetectorParameters has changed
    - start work on get_ready.sh to get Pi ready to run, including setting up Venv with necessary packages (rather than installing manually)
    [behavioral_metrics.py, eclc_temp_utils.py, python-recording-functions.py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]
